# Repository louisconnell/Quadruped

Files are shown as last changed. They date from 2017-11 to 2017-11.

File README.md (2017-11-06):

Firmwares
---

Development tools
---
- [Arduino IDE (Integrated Development Environment)](https://www.arduino.cc/)

Bugs and enhancements
---

To report a *bug* in the software or to request *a simple enhancement* contact the [developers](mailto:contact.fabtronic@artilect.fr)

If you're interested in modifying or extending the quad_robot software or hardware, we strongly suggest discussing your ideas whit the developers *before* starting to work on them. That way you can coordinate with the quad_robot Team and others, giving your work a higher chance of being integrated into the official release.

Credits
---
Project of:
- [Louis Mariau-Connell ](https://github.com/louisconnell/Quadruped)

License
---
[MIT License

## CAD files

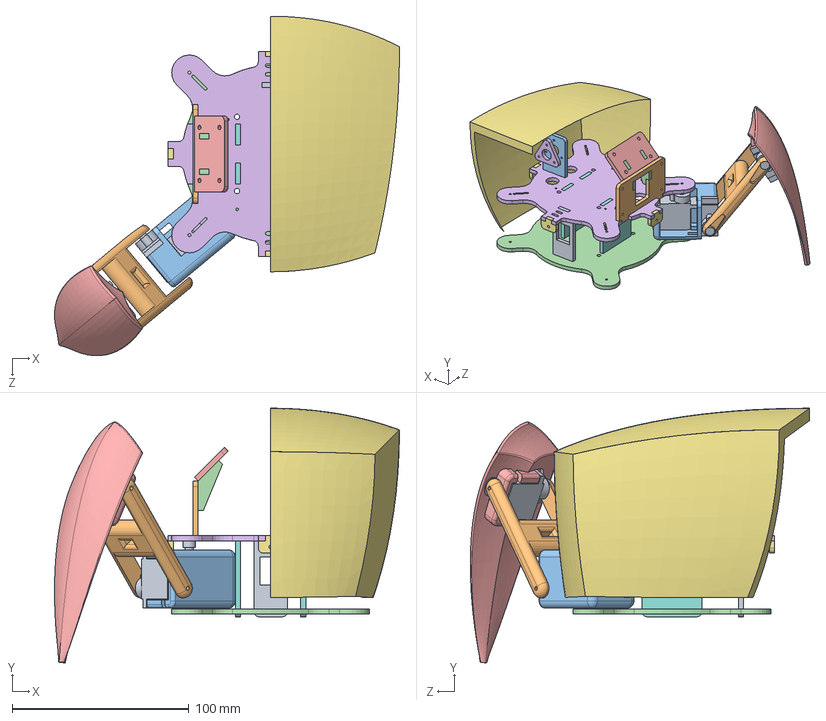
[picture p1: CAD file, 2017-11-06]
Solidworks parts/Assemblage quadruped.SLDASM
195.1 x 144.0 x 192.0 mm
servo motor x 3
Femur Quadruped
Coxa Quadruped V2
Base Quadruped Bas
Tibia Quadruped
Base Quadruped Haut
Bas Quadruped support capot x 4
Base Quadruped support batterie x 2
Base Quadruped support interrupteur
Base Quadruped support regulateur 1
Base Quadruped support antenne
Base Qudruped attache regulateurs x 2
Base Quadruped support régulateur 2
Base Quadruped support antenne 2
Capot Quadruped

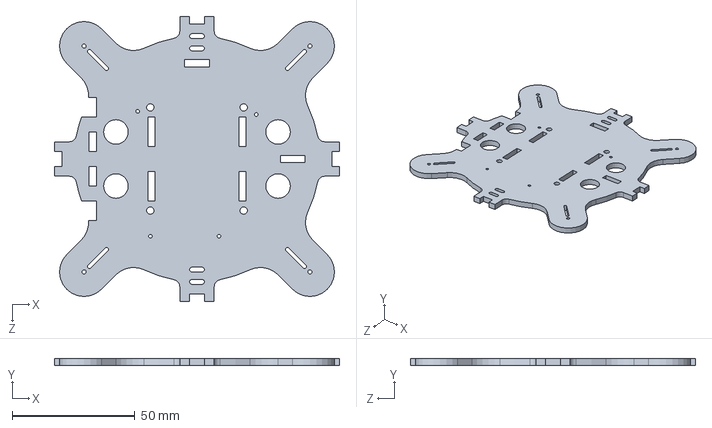
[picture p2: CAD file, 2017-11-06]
Solidworks parts/Base Quadruped Haut.SLDPRT
116.0 x 3.00 x 116.0 mm

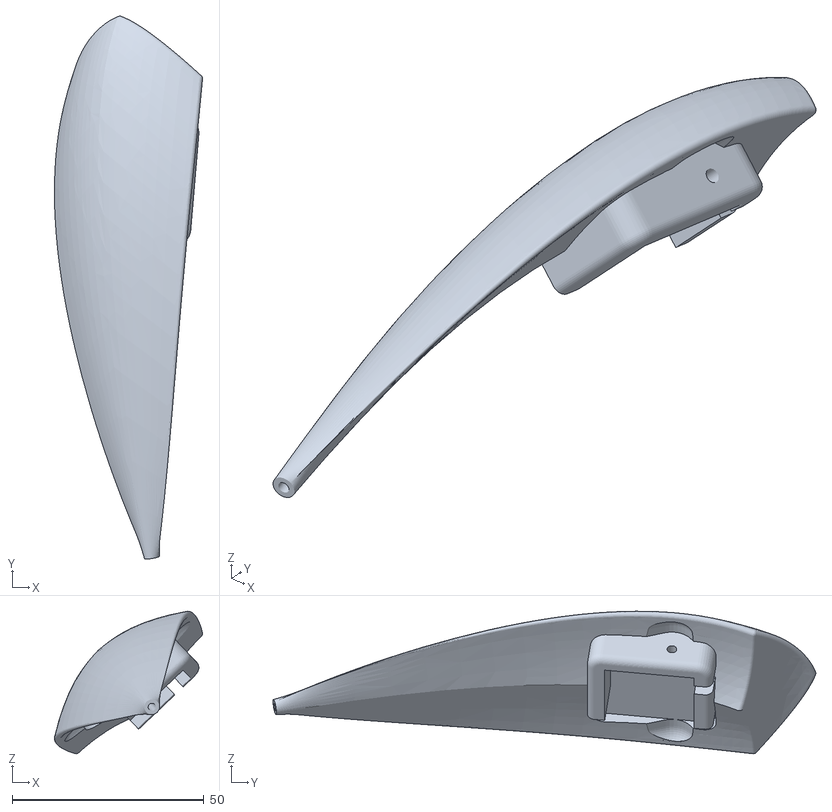
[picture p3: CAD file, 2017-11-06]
Tibia Quadruped-1.STL
38.6 x 141.5 x 37.1

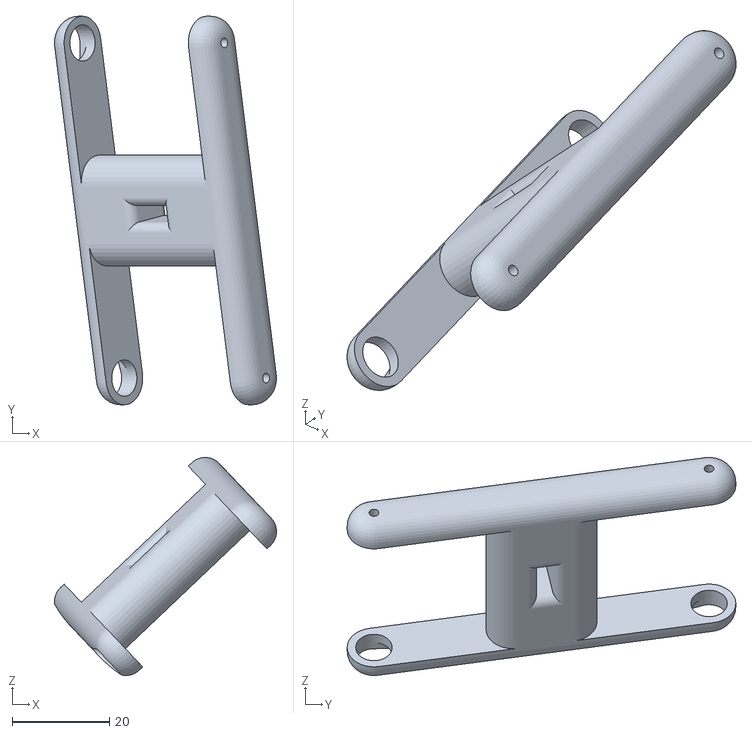
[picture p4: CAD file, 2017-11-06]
Femur Quadruped-1.STL
45.6 x 79.9 x 44.8

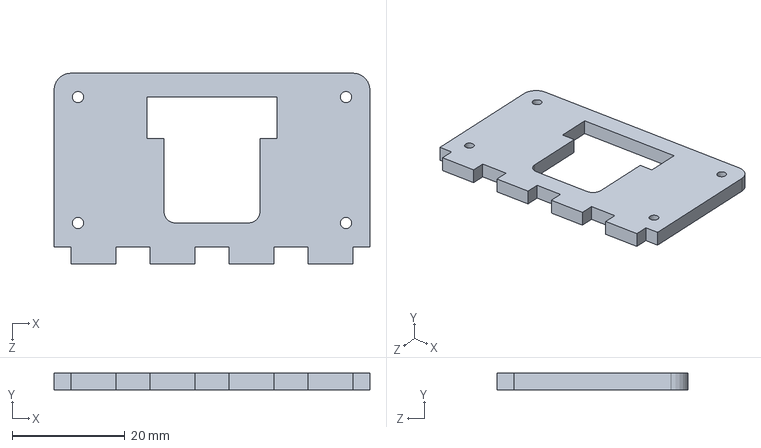
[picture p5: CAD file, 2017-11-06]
Solidworks parts/Base Quadruped support regulateur 1.SLDPRT
56.0 x 3.00 x 33.8 mm

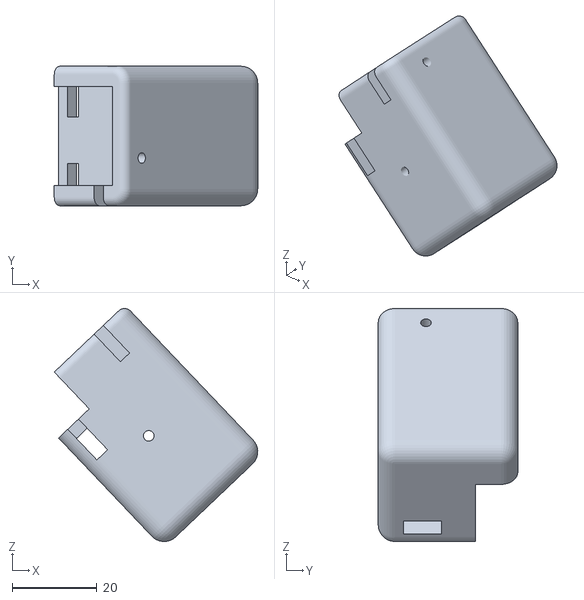
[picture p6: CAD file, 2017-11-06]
Coxa Quadruped-1.STL
48.1 x 33.0 x 55.0

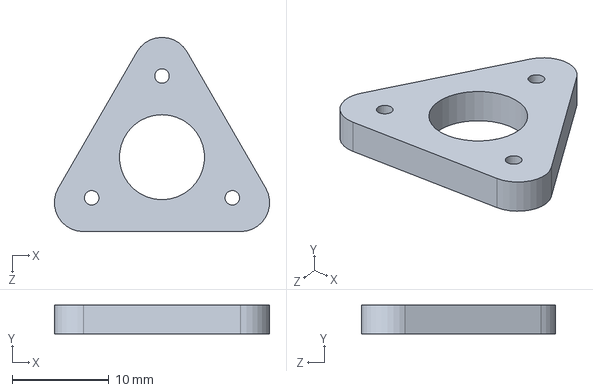
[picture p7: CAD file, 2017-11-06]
Solidworks parts/Base Quadruped support antenne 2.SLDPRT
22.2 x 3.00 x 20.1 mm

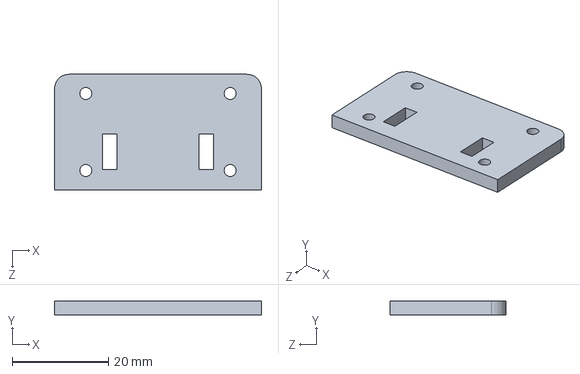
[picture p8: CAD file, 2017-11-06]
Solidworks parts/Base Quadruped support régulateur 2.SLDPRT
43.0 x 3.00 x 24.0 mm

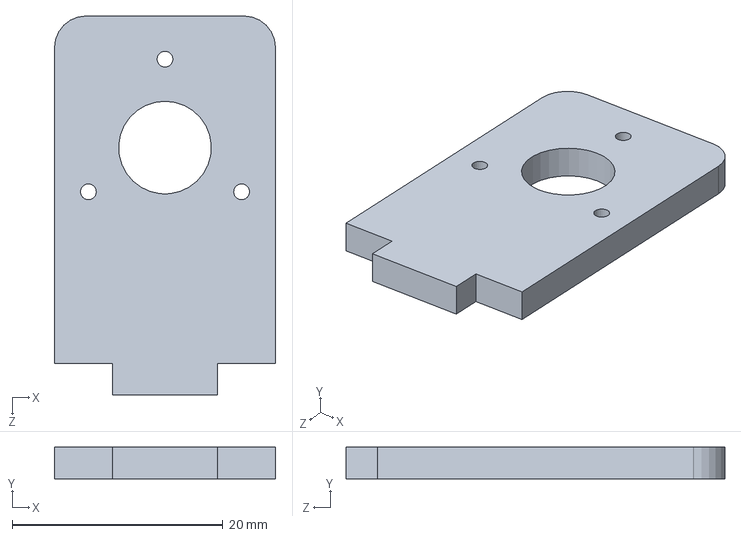
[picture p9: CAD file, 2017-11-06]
Solidworks parts/Base Quadruped support antenne.SLDPRT
21.0 x 3.00 x 36.0 mm

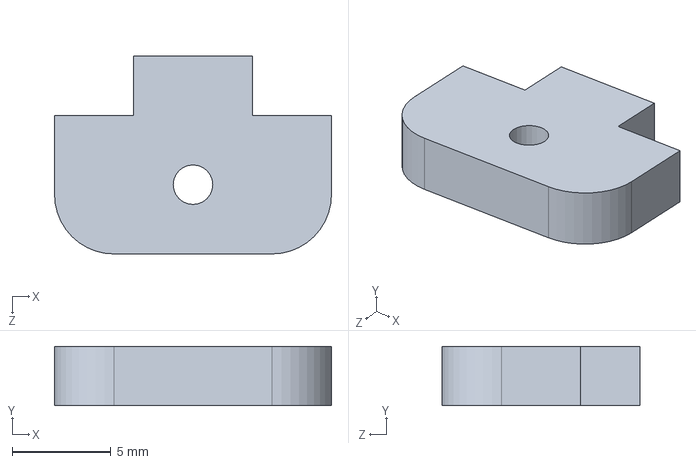
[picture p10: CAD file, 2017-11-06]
Solidworks parts/Bas Quadruped support capot.SLDPRT
14.0 x 3.00 x 10.0 mm

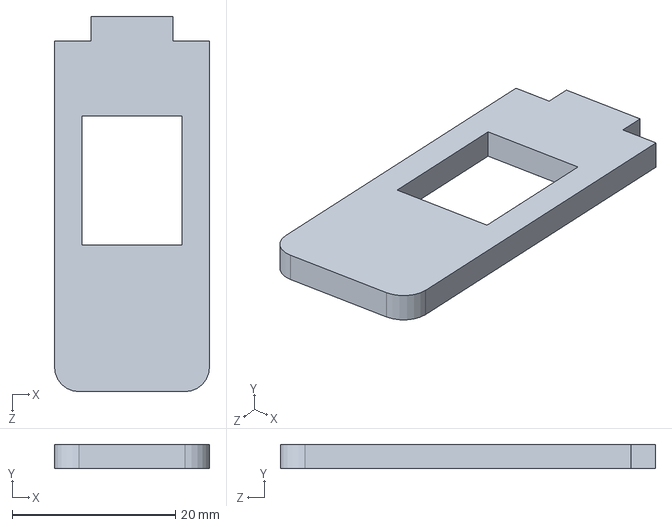
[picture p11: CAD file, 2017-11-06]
Solidworks parts/Base Quadruped support interrupteur.SLDPRT
19.0 x 3.00 x 46.0 mm

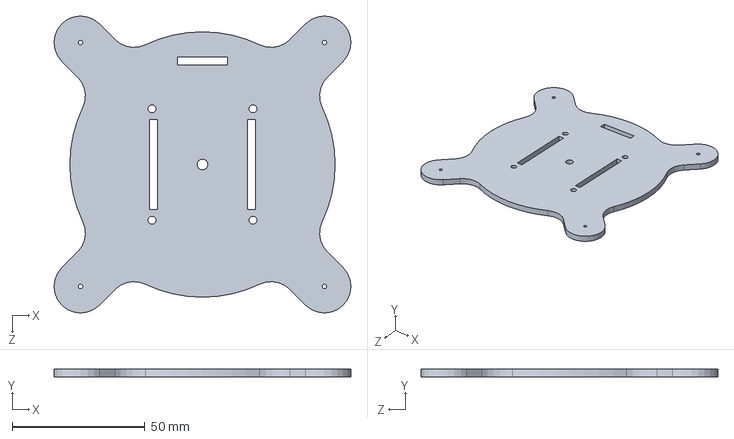
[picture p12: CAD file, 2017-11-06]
Solidworks parts/Base Quadruped Bas.SLDPRT
111.9 x 3.00 x 111.9 mm

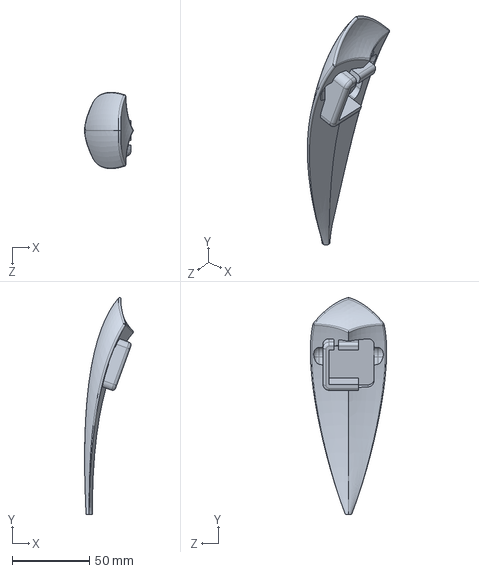
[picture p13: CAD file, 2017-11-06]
Solidworks parts/Tibia Quadruped.SLDPRT
31.5 x 140.2 x 49.3 mm

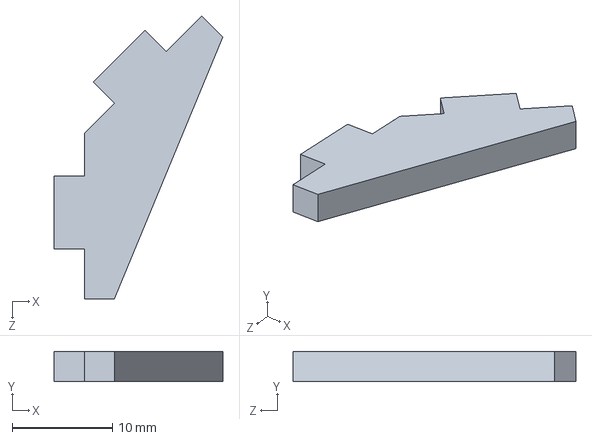
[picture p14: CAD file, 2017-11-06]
Solidworks parts/Base Qudruped attache regulateurs.SLDPRT
16.8 x 3.00 x 28.3 mm

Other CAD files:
Solidworks parts/Capot Quadruped.SLDPRT
Solidworks parts/Femur Quadruped.SLDPRT
Solidworks parts/Coxa Quadruped V2.SLDPRT
Solidworks parts/servo motor.SLDPRT
Solidworks parts/Base Quadruped support batterie.SLDPRT

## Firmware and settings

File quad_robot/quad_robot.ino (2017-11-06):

/*
  Original project by Louis Mariau-Connell (september 2017)
  https://github.com/louisconnell/Quadruped

  Hardware requirements:
  - 1x Arduino Nano
  https://store.arduino.cc/arduino-nano
  http://hardware-libre.fr/2014/07/arduino-le-nano-officiel/
  - 1x Adafruit 16-Channel 12-bit PWM/Servo Driver - I2C interface - PCA9685 (PRODUCT ID: 815)
  https://www.adafruit.com/product/815
  - 12x SG92R Micro Servo Moteur Nylon Engrenages En fiber de Carbone
  https://fr.aliexpress.com/item/1PCS-SG92R-Digital-Micro-Servo-Motor-Nylon-Carbon-fiber-Gears-For-RC-Model-Aeromodelling-Helicopter-Parts/32356224677.html

  External dependencies:
  - "Adafruit PWM Servo Driver Library" by Adafruit
  https://github.com/adafruit/Adafruit-PWM-Servo-Driver-Library
*/

#include <math.h>
#include <Wire.h>
#include <Adafruit_PWMServoDriver.h>

Adafruit_PWMServoDriver pwm = Adafruit_PWMServoDriver(0x40); /* 0x40 is the 7-bits I2C adresse of the "Adafruit 16-Channel 12-bit PWM/Servo Driver" board */

//servo specs
#define MIN_PULSE_WIDTH    400 //in micro seconds
#define MAX_PULSE_WIDTH   2400 //in micro seconds
#define FREQUENCY           50 //Hz, or a period of 20 ms

//robot dimensions (Geometric dimensions of a robot leg)
#define CoxaLength     20
#define FemurLength    70
#define TibiaLength   106

//servo naming
int Coxas[] = {0, 3, 6, 9};
int Femurs[] = {1, 4, 7, 10};
int Tibias[] = {2, 5, 8, 11};
int DegreeCoxas[4];
int DegreeFemurs[4];
int DegreeTibias[4];

//commands for direction and rotation of body
int dirX = 0;
int dirY = 0;
int dirZ = 0;
int rotZ = 0;

//x y z positions for next step
int neutralX = 65;
int neutralY = 65;
int neutralZ = 70;
int nextX = neutralX;
int nextY = neutralY;
int nextZ = neutralZ;

//x y positions for rotations
int nextX2;
int nextY2;

//maximum steping lengths (140 max)
int maxStepLength = 110; //max steping length (140mm max)
int maxHeightLength = 30; //max body height length (30mm max)
int legLift = 30; //leg lifting height

//delay time for slower walking cycle
int cycleSpeed = 5;

//leg index for walking gait incrementing each leg 128 steps in 1 cycle
unsigned int legIndex = 0;
//leg coordinates inverting
int WHATLEG_X = 0;
int WHATLEG_Y = 0;

//analog values for PWM sent to servo
int analog_value;
int ANALOG_MIN = 4095 / (20000 / MIN_PULSE_WIDTH);
int ANALOG_MAX = 4095 / (20000 / MAX_PULSE_WIDTH);

void setup() {
  Serial.begin(115200); /* Attention to the speed of serial communication, the many information exchange to the PC can slow down the main loop and thus make the robot slower. */
  pwm.begin();
  pwm.setPWMFreq(FREQUENCY);

  delay(1000);

  InverseKinematics(0, nextX, nextY, nextZ);
  InverseKinematics(1, nextX, nextY, nextZ);
  InverseKinematics(2, nextX, nextY, nextZ);
  InverseKinematics(3, nextX, nextY, nextZ);
}

void loop() {
  ReceiveCommand();

  WHATLEG_X = 0;
  WHATLEG_Y = 0;
  WalkingCycle();
  Serial.print("Leg 0 coordinates : X:");
  Serial.print(nextX);
  Serial.print(" Y:");
  Serial.print(nextY);
  Serial.print(" Z:");
  Serial.println(nextZ);
  Serial.print("LegIndex0: ");
  Serial.println(legIndex);
  if (rotZ != 0) {
    InverseKinematics(0, nextX2, nextY2, nextZ);
  }
  else if (rotZ == 0) {
    InverseKinematics(0, nextX, nextY, nextZ);
  }

  legIndex = (legIndex + 31) % 128; //+31 for taking into account increment inside walking cycle
  WHATLEG_X = 1;
  WHATLEG_Y = 1;
  WalkingCycle();
  InverseKinematics(2, nextX, nextY, nextZ);

  legIndex = (legIndex + 31) % 128; //+31 for taking into account increment inside walking cycle
  WHATLEG_X = 1;
  WHATLEG_Y = 0;
  WalkingCycle();
  InverseKinematics(1, nextY, nextX, nextZ);

  legIndex = (legIndex + 31) % 128; //+31 for taking into account increment inside walking cycle
  WHATLEG_X = 0;
  WHATLEG_Y = 1;
  WalkingCycle();
  InverseKinematics(3, nextY, nextX, nextZ);

  legIndex = (legIndex + 32) % 128;

  pwm.setPWM(Coxas[0], 0, pulseWidthInverse(DegreeCoxas[0]) - 10);
  pwm.setPWM(Femurs[0], 0, pulseWidthInverse(DegreeFemurs[0]) - 2);
  pwm.setPWM(Tibias[0], 0, pulseWidthInverse(DegreeTibias[0]) - 4);
  pwm.setPWM(Coxas[1], 0, pulseWidthInverse(DegreeCoxas[1]) - 4);
  pwm.setPWM(Femurs[1], 0, pulseWidthNormal(DegreeFemurs[1]) - 4);
  pwm.setPWM(Tibias[1], 0, pulseWidthNormal(DegreeTibias[1]) + 3);
  pwm.setPWM(Coxas[2], 0, pulseWidthInverse(DegreeCoxas[2]) - 12);
  pwm.setPWM(Femurs[2], 0, pulseWidthInverse(DegreeFemurs[2]) - 6);
  pwm.setPWM(Tibias[2], 0, pulseWidthInverse(DegreeTibias[2]) - 22);
  pwm.setPWM(Coxas[3], 0, pulseWidthInverse(DegreeCoxas[3]) + 4);
  pwm.setPWM(Femurs[3], 0, pulseWidthNormal(DegreeFemurs[3]) + 4);
  pwm.setPWM(Tibias[3], 0, pulseWidthNormal(DegreeTibias[3]) + 14);
  delay(cycleSpeed);
  Serial.println();
}

//------------------------------------------------------------------------
void ReceiveCommand() { //walking command from controller
  //eventually analog inputs from controler. for now values from -100 to 100 in each direction
  dirX = 0; //+100 move right at high speed, -100 move left at high speed
  dirY = 100; //+100 move forward at high speed, -100 move backward at high speed
  dirZ = 0; //+100 body higher up to threshold, -100 body lower up to threshold
  rotZ = 0; //+100 rotate right at high speed, -100 rotate left at high speed
  Serial.println("Command");
}

//-------------------------------------------------------------------------
void WalkingCycle() { //define what step in each leg cycle and what position each leg has to take
  if (legIndex < 96) {
    if (dirX > 0 || 0 > dirX) {
      int StepLength = dirX;
      if (WHATLEG_X == 0) {
        StepLength = map(StepLength, -100, 100, -maxStepLength, maxStepLength); //defining step length in mm
      }
      if (WHATLEG_X == 1) {
        StepLength = map(StepLength, -100, 100, maxStepLength, -maxStepLength);
      }
      int StepX = legIndex * abs(StepLength) / 96; //giving x position in step length
      int StepMinPos = neutralX - (StepLength / 2); //defining x coordinates of begining of step
      int StepMaxPos = neutralX + (StepLength / 2); //defining x coordinates of end of step
      nextX = map (StepX, 0, abs(StepLength), StepMinPos, StepMaxPos); //new x position
    }
    if (dirY > 0 || 0 > dirY) {
      int StepLength = dirY;
      if (WHATLEG_Y == 0) {
        StepLength = map(StepLength, -100, 100, -maxStepLength, maxStepLength); //defining step length in mm
      }
      if (WHATLEG_Y == 1) {
        StepLength = map(StepLength, -100, 100, maxStepLength, -maxStepLength);
      }
      int StepY = legIndex * abs(StepLength) / 96; //giving y position in step length
      int StepMinPos = neutralY - (StepLength / 2); //defining y coordinates of begining of step
      int StepMaxPos = neutralY + (StepLength / 2); //defining y coordinates of end of step
      nextY = map (StepY, 0, abs(StepLength), StepMinPos, StepMaxPos); //new y position
    }
  }
  else if (96 <= legIndex) { //LEG LIFTING MOTION
    if (dirX > 0 || 0 > dirX) {
      int StepLength = dirX;
      if (WHATLEG_X == 0) {
        StepLength = map(StepLength, -100, 100, -maxStepLength, maxStepLength); //defining step length in mm
      }
      if (WHATLEG_X == 1) {
        StepLength = map(StepLength, -100, 100, maxStepLength, -maxStepLength);
      }
      int StepX = (legIndex - 96) * abs(StepLength) / 32; //giving x position in step length
      int StepMinPos = neutralX + (StepLength / 2); //defining x coordinates of begining of step
      int StepMaxPos = neutralX - (StepLength / 2); //defining x coordinates of end of step
      nextX = map (StepX, 0, abs(StepLength), StepMinPos, StepMaxPos); //new x position
    }
    if (dirY > 0 || 0 > dirY) {
      int StepLength = dirY;
      if (WHATLEG_Y == 0) {
        StepLength = map(StepLength, -100, 100, -maxStepLength, maxStepLength); //defining step length in mm
      }
      if (WHATLEG_Y == 1) {
        StepLength = map(StepLength, -100, 100, maxStepLength, -maxStepLength);
      }
      int StepY = (legIndex - 96) * abs(StepLength) / 32; //giving y position in step length
      int StepMinPos = neutralY + (StepLength / 2); //defining y coordinates of begining of step
      int StepMaxPos = neutralY - (StepLength / 2); //defining y coordinates of end of step
      nextY = map (StepY, 0, abs(StepLength), StepMinPos, StepMaxPos); //new y position
    }
  }

  int BodyHeight = dirZ;
  if (dirZ > 0 || 0 > dirZ) {
    BodyHeight = map(BodyHeight, -100, 100, -maxHeightLength, maxHeightLength);
    nextZ = neutralZ + BodyHeight; // Z COORDINATE TO SEND TO IK for
  }

  if (legIndex < 96) { // Z COORDINATE TO SEND TO IK for keeping leg on ground
    nextZ = neutralZ + BodyHeight;
  }
  else if (96 <= legIndex && dirX != 0 || dirY != 0) {
    nextZ = 0.1 * sq(legIndex - 112) - legLift + (neutralZ + BodyHeight); // Z COORDINATE TO SEND TO IK for lift parabola
  }
  /*
    if (legIndex < 96) {
      if (rotZ > 0 || 0 > rotZ) {
        Serial.println("walking cycle rotZ");
        float RotSpeed = map_float(rotZ, -100, 100, -HALF_PI, HALF_PI); //define angle step length
        Serial.println(RotSpeed);
        float RotAngle = legIndex * (RotSpeed / 96); //giving angle position in step length
        Serial.println(RotAngle);
        float CurCoxaAngle = atan2(nextY, nextX); //coxa angle after translation movement
        Serial.println(CurCoxaAngle);
        float LegLength = sqrt(sq(nextX) + sq(nextY));
        Serial.println(LegLength);
        nextX2 = nextX + ((LegLength * cos(CurCoxaAngle + RotAngle)) - neutralX); // X COORDINATE TO SEND TO IK
        Serial.print("walking cycle nextX ROT ");
        Serial.println(nextX2);
        nextY2 = nextY + ((LegLength * sin(CurCoxaAngle + RotAngle)) - neutralY); // Y COORDINATE TO SEND TO IK
        Serial.print("walking cycle nextY ROT ");
        Serial.println(nextY2);
      }
    }
    if (legIndex <= 96) {
      if (rotZ > 0 || 0 > rotZ) {
        Serial.println("walking cycle rotZ");
        float RotSpeed = map_float(rotZ, -100, 100, HALF_PI, -HALF_PI); //define angle step length
        Serial.println(RotSpeed);
        float RotAngle = (legIndex - 96) * (RotSpeed / 32); //giving angle position in step length
        Serial.println(RotAngle);
        float CurCoxaAngle = atan2(nextY, nextX); //coxa angle after translation movement
        Serial.println(CurCoxaAngle);
        float LegLength = sqrt(sq(nextX) + sq(nextY));
        Serial.println(LegLength);
        nextX2 = nextX + ((LegLength * cos(CurCoxaAngle + RotAngle)) - neutralX); // X COORDINATE TO SEND TO IK
        Serial.print("walking cycle nextX ROT ");
        Serial.println(nextX2);
        nextY2 = nextY + ((LegLength * sin(CurCoxaAngle + RotAngle)) - neutralY); // Y COORDINATE TO SEND TO IK
        Serial.print("walking cycle nextY ROT ");
        Serial.println(nextY2);
      }
    }*/

  legIndex = (legIndex + 1) % 128; // individual leg indexes automatically update
}

float map_float(float val, float in_min, float in_max, float out_min, float out_max) {
  return (val - in_min) * (out_max - out_min) / (in_max - in_min) + out_min;
}

int pulseWidthNormal(int radian) {
  analog_value = map(radian, 0, 3141, ANALOG_MIN, ANALOG_MAX);
  return analog_value;
}

int pulseWidthInverse(int radian) {
  analog_value = map(radian, 3141, 0, ANALOG_MIN, ANALOG_MAX);
  return analog_value;
}

//-----------------------------------------------------------------------
void InverseKinematics(int numPatte, int x, int y, int z) { //inverse kinematics calculating next x y z position for each leg
  //--------------------------leg IK---------------------
  float CoxaAngle = atan2(y, x);
  float LegLength = sqrt(sq(x) + sq(y));
  float Hf = sqrt(sq(LegLength - CoxaLength) + sq(z));
  float A1 = atan2(LegLength - CoxaLength, z);
  float A2 = acos((sq(TibiaLength) - sq(FemurLength) - sq(Hf)) / (-2 * FemurLength * Hf));
  float FemurAngle = HALF_PI - (A1 + A2);
  float C1 = acos((sq(Hf) - sq(TibiaLength) - sq(FemurLength)) / (-2 * FemurLength * TibiaLength));
  float TibiaAngle = HALF_PI - C1;

  DegreeCoxas[numPatte] = (CoxaAngle + (HALF_PI / 2)) * 1000; //Coxa in radians x1000
  DegreeFemurs[numPatte] = (FemurAngle + (HALF_PI)) * 1000; //Femur in radians x1000
  DegreeTibias[numPatte] = ((HALF_PI) - TibiaAngle) * 1000; //Tibia in radians x1000
}

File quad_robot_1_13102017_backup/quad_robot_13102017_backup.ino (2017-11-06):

#include <math.h>
#include <Wire.h>
#include <Adafruit_PWMServoDriver.h>

Adafruit_PWMServoDriver pwm = Adafruit_PWMServoDriver(0x40);

//servo specs
#define MIN_PULSE_WIDTH 400 //in micro seconds
#define MAX_PULSE_WIDTH 2400 //in micro seconds
#define FREQUENCY 50 //Hz

#define CoxaLength 20
#define FemurLength 70
#define TibiaLength 106

int Coxas[] = {0, 3, 6, 9};
int Femurs[] = {1, 4, 7, 10};
int Tibias[] = {2, 5, 8, 11};

int DegreeCoxas[4];
int DegreeFemurs[4];
int DegreeTibias[4];

// leg positions
int x = 60;
int y = 60;
int z = 70;

//comands for direction and rotation of body
int ComDirX = 0;
int ComDirY = 0;
int ComDirZ = 0;
int ComRotZ = 0;

//leg index for walking gait incrementing each leg 128 steps in 1 cycle
int legIndex = 0;
int LB = legIndex;
int RB = legIndex + 32;
int RF = legIndex + 64;
int LF = legIndex + 96;

//analog values for PWM sent to servo
int analog_value;
int ANALOG_MIN = 4095 / (20000 / MIN_PULSE_WIDTH);
int ANALOG_MAX = 4095 / (20000 / MAX_PULSE_WIDTH);

//controller input
int CommandInput;

void setup() {
  Serial.begin(115200);
  pwm.begin();
  pwm.setPWMFreq(FREQUENCY);

  delay(1000);
}

void loop() {
  ReceiveCommand(ComDirX, ComDirY, ComDirZ, ComRotZ);
  Serial.println(ComDirX);
  ComDirY = 100;
  Serial.println(ComDirY);
  Serial.println(ComDirZ);
  Serial.println(ComRotZ);
  WalkingCycle(x, y, z);

  InverseKinematics(0, x, y, z);
  pwm.setPWM(Coxas[0], 0, pulseWidthInverse(DegreeCoxas[0]));
  pwm.setPWM(Femurs[0], 0, pulseWidthInverse(DegreeFemurs[0]));
  pwm.setPWM(Tibias[0], 0, pulseWidthInverse(DegreeTibias[0]));
}

//------------------------------------------------------------------------
//walking command from controller
void ReceiveCommand(int dirX, int dirY, int dirZ, int rotZ) {
  if (Serial.available() > 0) {
    CommandInput = Serial.read();
    if (CommandInput == 0) {
      dirX = 0;
      dirY = 0;
      dirZ = 0;
      rotZ = 0;
    }
     else if (CommandInput == 0) {
      //eventually analog inputs from controler. for now values from -100 to 100 in each direction
      dirX = 0; //+100 move right at high speed, -100 move left at high speed
      dirY = 100; //+100 move forward at high speed, -100 move backward at high speed
      dirZ = 0; //+100 body higher up to threshold, -100 body lower up to threshold
      rotZ = 0; //+100 rotate right at high speed, -100 rotate left at high speed
    }
  }
  Serial.print("Command ");
  Serial.println(CommandInput);
}

//-------------------------------------------------------------------------
//define what step in each leg cycle and what position each leg has to take
void WalkingCycle(int nextX, int nextY, int nextZ) {
  if (ComDirZ > 0 > ComDirZ) {
    int BodyHeight = ComDirZ;
    map(BodyHeight, -100, 100, -30, 30);
    nextZ = z + BodyHeight; // Z COORDINATE TO SEND TO IK
  }
  if (legIndex < 96) {
    if (ComDirX > 0 > ComDirX) { //
      int StepLength = ComDirX;
      map(StepLength, -100, 100, -140, 140); //defining step length in mm
      int StepX = legIndex * sqrt(sq(StepLength)) / 96; //giving x position in step length
      int StepMinPos = 60 - (StepLength / 2); //defining x coordinates of begining of step
      int StepMaxPos = 60 - (StepLength / 2); //defining x coordinates of end of step
      nextX = StepX;
      map (nextX, 0, StepLength, StepMinPos, StepMaxPos); //new x position
    }
    if (ComDirY > 0 > ComDirY) {
      int StepLength = ComDirY;
      map(StepLength, -100, 100, -140, 140); //defining step length in mm
      int StepY = legIndex * sqrt(sq(StepLength)) / 96; //giving y position in step length
      int StepMinPos = 60 - (StepLength / 2); //defining y coordinates of begining of step
      int StepMaxPos = 60 - (StepLength / 2); //defining y coordinates of end of step
      nextY = StepY;
      map (nextY, 0, StepLength, StepMinPos, StepMaxPos); //new y position
    }
    nextX = ((nextX - 60) / 2) + 60; //next x position for front back and translate movement combination
    nextY = ((nextY - 60) / 2) + 60; //next y position for front back and translate movement combination
    legIndex = (legIndex + 1) % 128; // individual leg indexes automatically update
  }
  else if (96 <= legIndex) {
    if (ComDirX > 0 > ComDirX) { //
      int StepLength = ComDirX;
      map(StepLength, -100, 100, 140, -140); //defining step length in mm
      int StepX = legIndex * sqrt(sq(StepLength)) / 32; //giving x position in step length
      int StepMinPos = 60 - (StepLength / 2); //defining x coordinates of begining of step
      int StepMaxPos = 60 - (StepLength / 2); //defining x coordinates of end of step
      nextX = StepX;
      map (nextX, 0, StepLength, StepMinPos, StepMaxPos); //new x position
    }
    if (ComDirY > 0 > ComDirY) {
      int StepLength = ComDirY;
      map(StepLength, -100, 100, 140, -140); //defining step length in mm
      int StepY = legIndex * sqrt(sq(StepLength)) / 32; //giving y position in step length
      int StepMinPos = 60 - (StepLength / 2); //defining y coordinates of begining of step
      int StepMaxPos = 60 - (StepLength / 2); //defining y coordinates of end of step
      nextY = StepY;
      map (nextY, 0, StepLength, StepMinPos, StepMaxPos); //new y position
    }
    nextZ = -0.1 * sq(legIndex - 112) + 20; // Z COORDINATE TO SEND TO IK for lift parabola
    nextX = ((nextX - 60) / 2) + 60; //next x position for front back and translate movement combination
    nextY = ((nextY - 60) / 2) + 60; //next y position for front back and translate movement combination
    legIndex = (legIndex + 1) % 128; // individual leg indexes automatically update
  }
  if (ComRotZ > 0 > ComRotZ) {
    int RotSpeed = ComRotZ;
    map (RotSpeed, -100, 100, -PI / 4, PI / 4);
    int RotAngle = RotSpeed / 64; //defining micro angle steps
    double CurCoxaAngle = atan2(nextY, nextX); //coxa angle after translation movement
    double LegLength = sqrt(sq(x) + sq(y));
    nextX = LegLength * cos(CurCoxaAngle + RotAngle); // X COORDINATE TO SEND TO IK
    nextY = LegLength * sin(CurCoxaAngle + RotAngle); // Y COORDINATE TO SEND TO IK
  }
}

int pulseWidthNormal(int radian) {
  analog_value = map(radian, 0, 3141, ANALOG_MIN, ANALOG_MAX);
  Serial.print("Servo analog value : ");
  Serial.println(analog_value);
  return analog_value;
}

int pulseWidthInverse(int radian) {
  analog_value = map(radian, 3141, 0, ANALOG_MIN, ANALOG_MAX);
  Serial.print("Servo analog value : ");
  Serial.println(analog_value);
  return analog_value;
}
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
